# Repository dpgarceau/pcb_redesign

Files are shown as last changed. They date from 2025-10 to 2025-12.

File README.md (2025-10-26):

# AeroJudge PCB Redesign - Board Consolidation Project

**Goal:** Merge two existing boards plus three sub-modules into a single Raspberry Pi 4 HAT for streamlined production.

This project consolidates a multi-board assembly into one functional HAT PCB suitable for commercial manufacturing (JLCPCB-A or similar).

## Project Overview

Currently, the AeroJudge system consists of:
- Main board (primary interface and controls)
- Power board with three mounted sub-modules
- Multiple interconnecting cables

**Target:** Single PCB design with all functionality integrated, ready for automated assembly.

## Files Included

- `Main_Board.kicad_pcb` / `Main_Board.kicad_sch` - Primary interface board
- `Power_Board.kicad_pcb` / `Power_Board.kicad_sch` - Power management board
- `Pololu_2810_Circuit.pdf` - Circuit diagram for power switch implementation
- Sub-board reference links and datasheets (see below)

## Main Board Changes

**Components to Remove:**
- ENC 1 (keep ENC2 only)
- GPIO16, GPIO12, GPIO23, GPIO18
- All I2C connectors except I2C-1 (which will be integrated on-board)
- Backside pads for poweroff select and shutdown select (replace with direct traces to GPIO24 and GPIO25)

## Power Board Integration

The power board currently uses three separate sub-modules that must be integrated directly onto the main PCB:

### 1. INA226 Current/Voltage Sensor
- Reference module: https://www.aliexpress.us/item/3256806274363321.html
- Function: Battery monitoring
- Designer should integrate equivalent circuit based on INA226 datasheet

### 2. Pololu 2810 Power Switch
- Circuit diagram provided: `Pololu_2810_Circuit.pdf`
- Use this circuit diagram to integrate switch functionality onto main board
- No pre-made module needed

### 3. Voltage Regulator (Requires Redesign)
- Current setup uses manual voltage adjustment (not optimal)
- **Requirements:** 5.1V DC output, 3+ Amp capability for Raspberry Pi 4
- **Options:**
  - Clone Pololu 4892 circuit (5V, 3.4A Step-Down Voltage Regulator D30V30F)
  - Design equivalent buck converter circuit
  - Designer should recommend specific components/circuit

**Power Input:**
- Replace current battery solder pads with appropriate DC power connector/plug
- Specify connector type in design

**Connectors Being Eliminated:**
All external connectors between boards become internal traces:
- I2C connectors
- Power/shutoff connectors  
- 5V battery connector

## Additional Requirements

### LED Connector
- Duplicate existing LED connector
- Add second connector for 3.3V LED operation
- Designer should specify connector types

### Physical Constraints
- Base on Raspberry Pi 4 HAT form factor (can be larger if needed - maximum size without case redesign shown in `AeroJudge_PCB-Size.pdf`, provide size recommendations if that is not large enough)
- **Connector height limit:** Approximately 5mm (90-degree connectors required for case clearance)
- Components can be on both sides of board
- **Avoid placing connectors on bottom side** (HAT clearance requirements)
- Existing case can be redesigned if necessary, but prefer to work within current constraints

### Board Markings
- Front: AeroJudge logo, website link, "Board Rev 3.0"
- Rear: IMAC logo (if space permits, not critical)

## Deliverables Expected

1. Complete KiCad project files (schematics + PCB layout)
2. Manufacturing-ready Gerber files
3. Bill of Materials (BOM) with specific part numbers
4. Assembly drawing/notes
5. Board size recommendations based on component layout

## Design Notes

- Target manufacturer: JLCPCB-A or similar automated assembly service
- All sub-assemblies must be eliminated - single PCB only
- Maintain all existing functionality from current two-board system
- Designer should flag any potential issues with integration approach

## Questions for Designer

Before starting, please confirm:
1. Are the provided sub-board references sufficient, or do you need additional datasheets?
2. What board dimensions do you recommend based on component density?
3. Any concerns about the voltage regulator redesign requirements?

## Contact

For questions or clarifications during design process, please contact me through upwork.

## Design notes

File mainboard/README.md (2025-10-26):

# AeroJudge PCB

Here you will find details and source files for the aerojudge main PCB.  This PCB can be used standalone or together with the Aerojudge Power PCB.
<picture>
  <source
    srcset="AeroJudge_PCB_Top.jpg"
    media="(orientation: landscape)" />
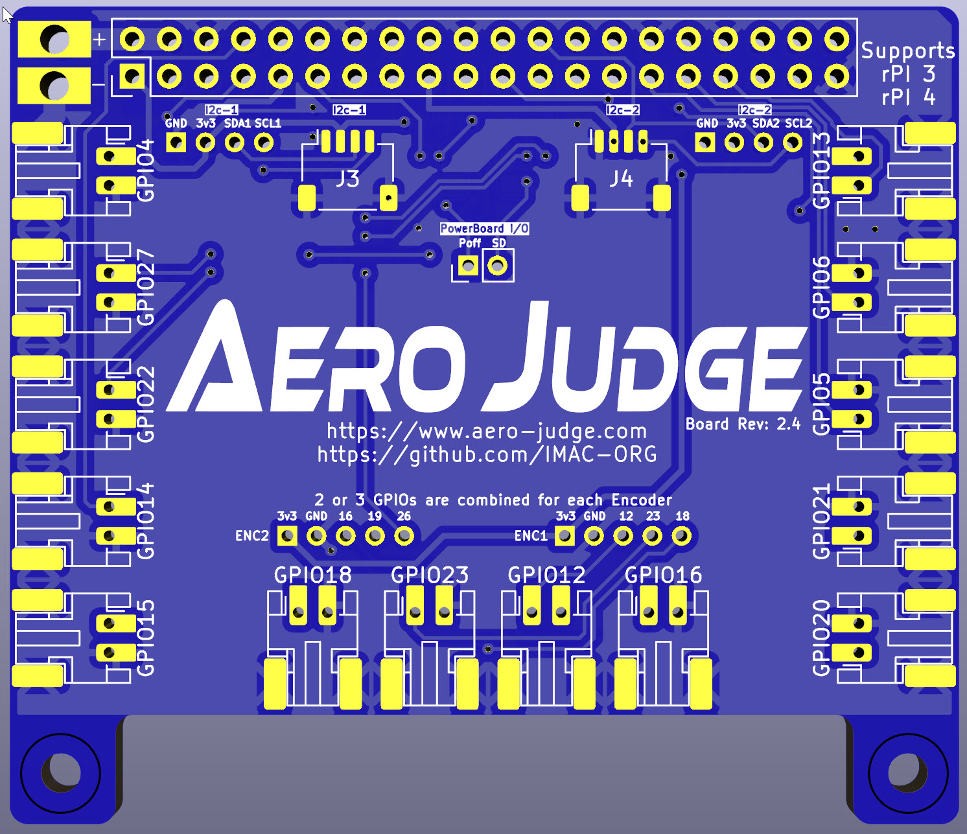
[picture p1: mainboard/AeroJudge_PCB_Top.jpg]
AeroJudge PCB Top
  
</picture>
<picture>
  <source
    srcset="AeroJudge_PCB_Bottom.jpg"
    media="(orientation: landscape)" />
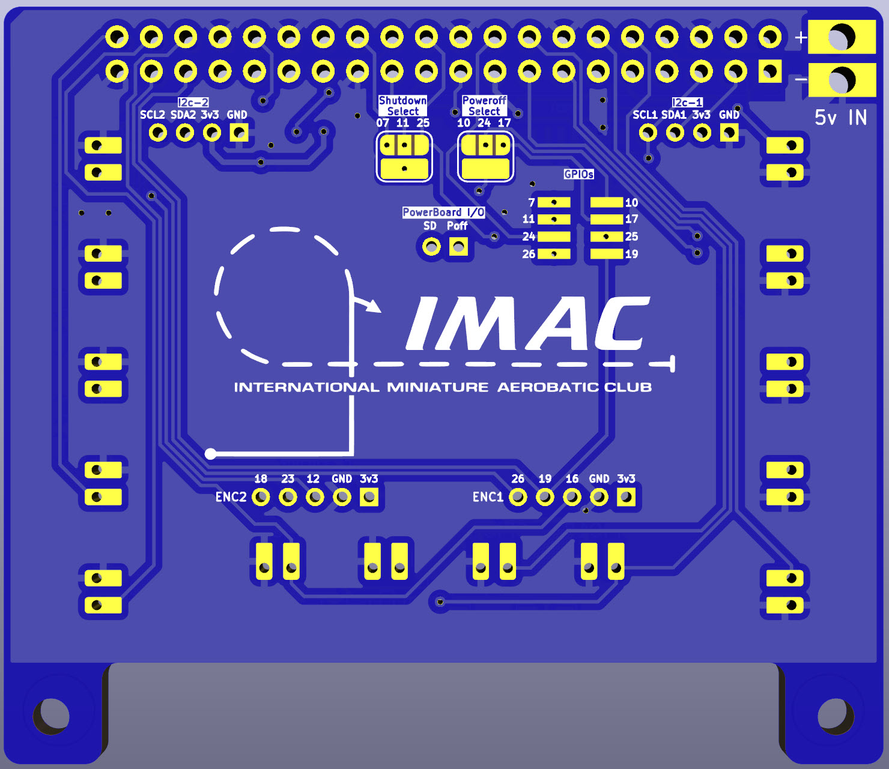
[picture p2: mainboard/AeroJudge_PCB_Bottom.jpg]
AeroJudge PCB Bottom
  
</picture>

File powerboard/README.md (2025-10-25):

# AeroJudge PCB

<picture>
  <source
    srcset="../..//Media/AeroJudge%20Logo/AeroJudge%20Logo.jpg"
    media="(orientation: landscape)" />
  AeroJudge
</picture>
<br>

Here you will find details and source files for the aerojudge powerboard PCB.  This PCB is used to house the power components of the device.

<picture>
  <source
    srcset="AeroJudge_Powerboard_PCB_Top.png"
    media="(orientation: landscape)" />
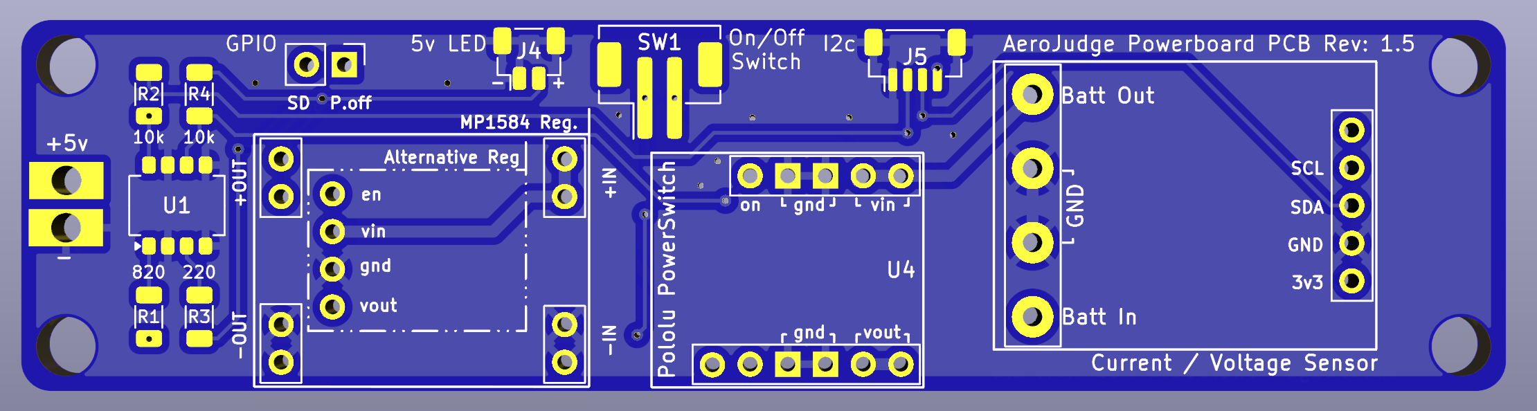
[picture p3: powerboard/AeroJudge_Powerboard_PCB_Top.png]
AeroJudge Powerboard PCB Top
  
</picture>
<picture>
  <source
    srcset="AeroJudge_Powerboard_PCB_Bottom.png"
    media="(orientation: landscape)" />
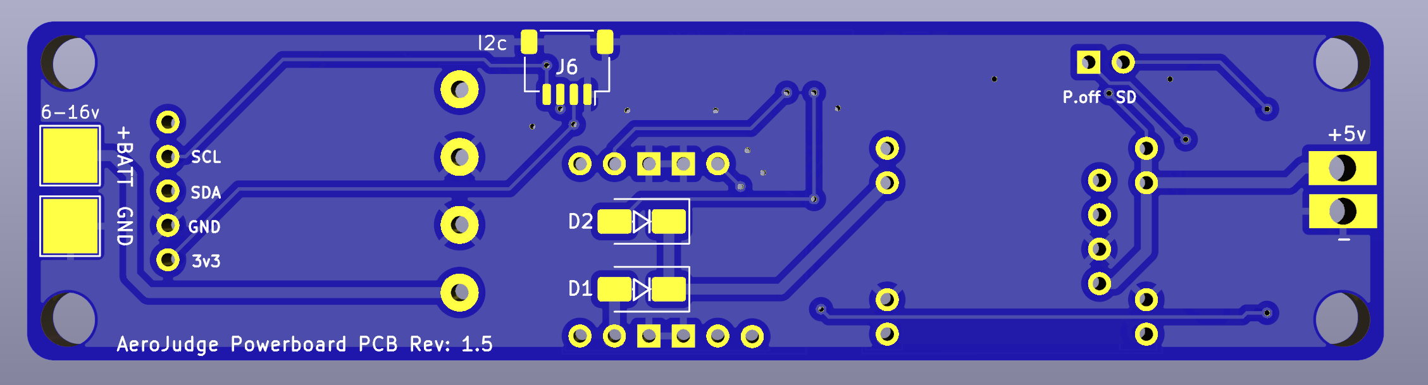
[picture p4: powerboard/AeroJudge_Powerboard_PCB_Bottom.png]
AeroJudge Powerboard PCB Bottom
  
</picture>
<br>

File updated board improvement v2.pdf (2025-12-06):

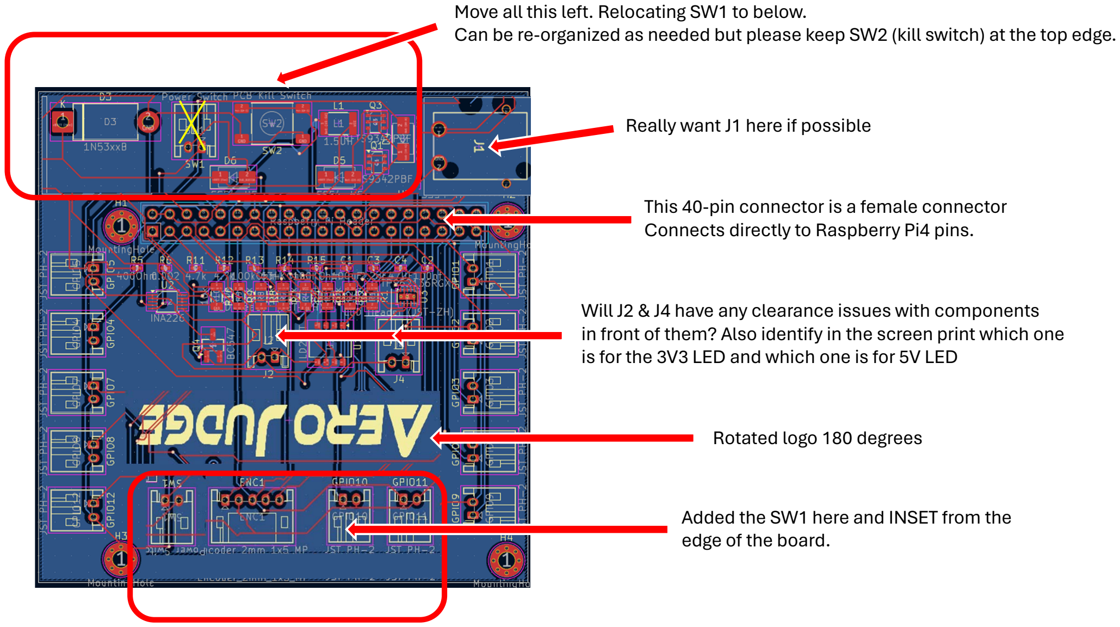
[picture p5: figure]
Really want J1 here if possible; Rotated logo 180 degrees; Added the SW1 here and INSET from the edge of the board.

Move all this left. Relocating SW1 to below.
Can be re-organized as needed but please keep SW2 (kill switch) at the top edge.

This 40-pin connector is a female connector Connects directly to Raspberry Pi4 pins.

Will J2 & J4 have any clearance issues with components in front of them? Also identify in the screen print which one is for the 3V3 LED and which one is for 5V LED

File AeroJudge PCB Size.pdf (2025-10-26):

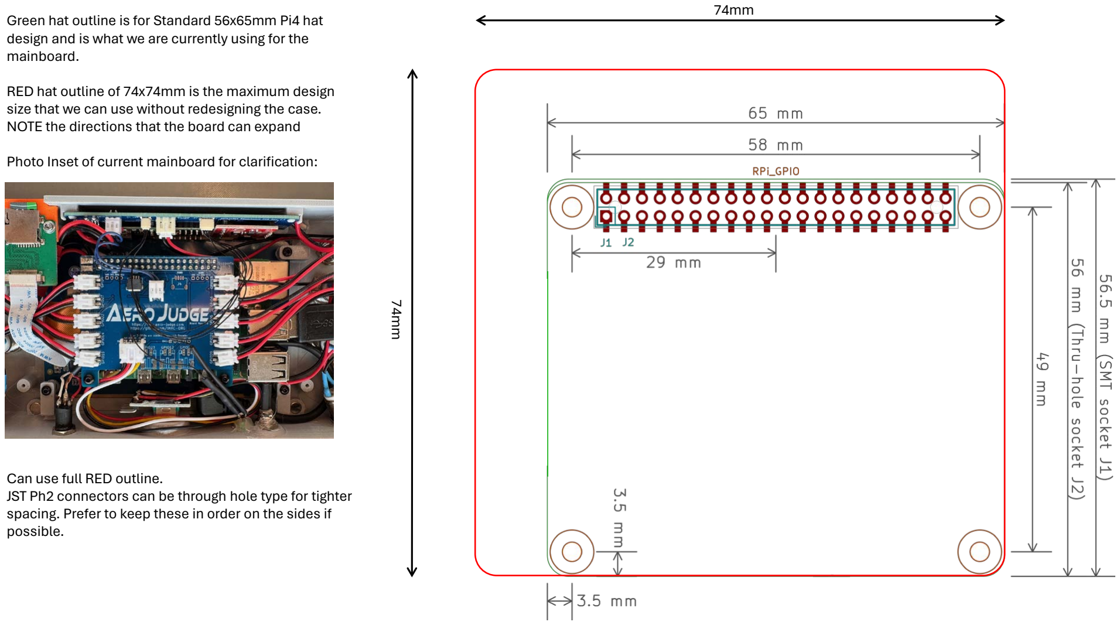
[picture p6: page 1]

74mm

74mm

Green hat outline is for Standard 56x65mm Pi4 hat design and is what we are currently using for the mainboard.

RED hat outline of 74x74mm is the maximum design size that we can use without redesigning the case. NOTE the directions that the board can expand

Photo Inset of current mainboard for clarification:

Can use full RED outline.
JST Ph2 connectors can be through hole type for tighter spacing. Prefer to keep these in order on the sides if possible.

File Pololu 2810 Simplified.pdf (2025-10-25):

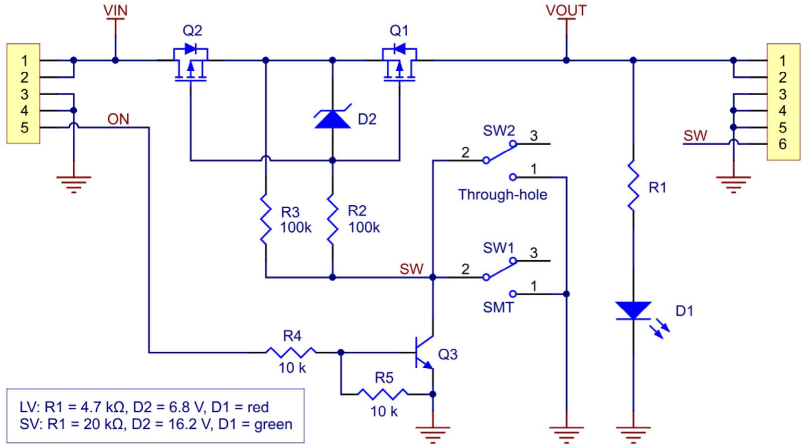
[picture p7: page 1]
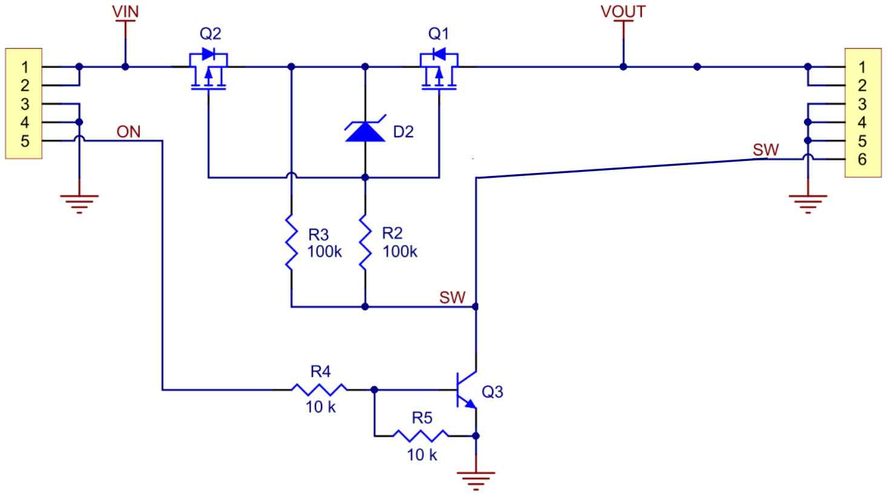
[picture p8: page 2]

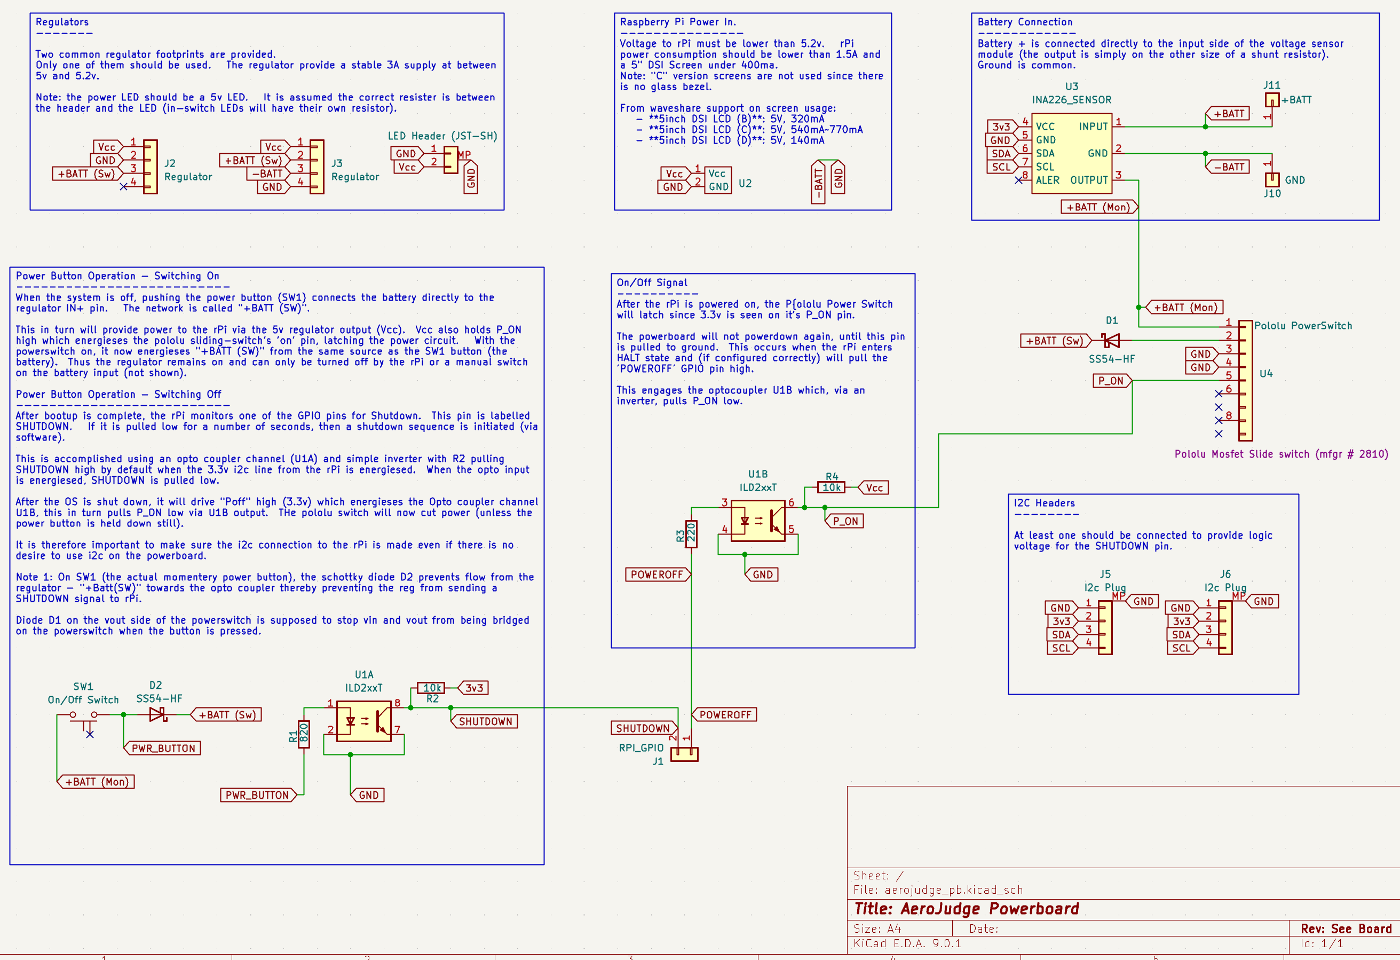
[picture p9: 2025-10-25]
powerboard/aerojudge_pb_SCHEMATIC.png

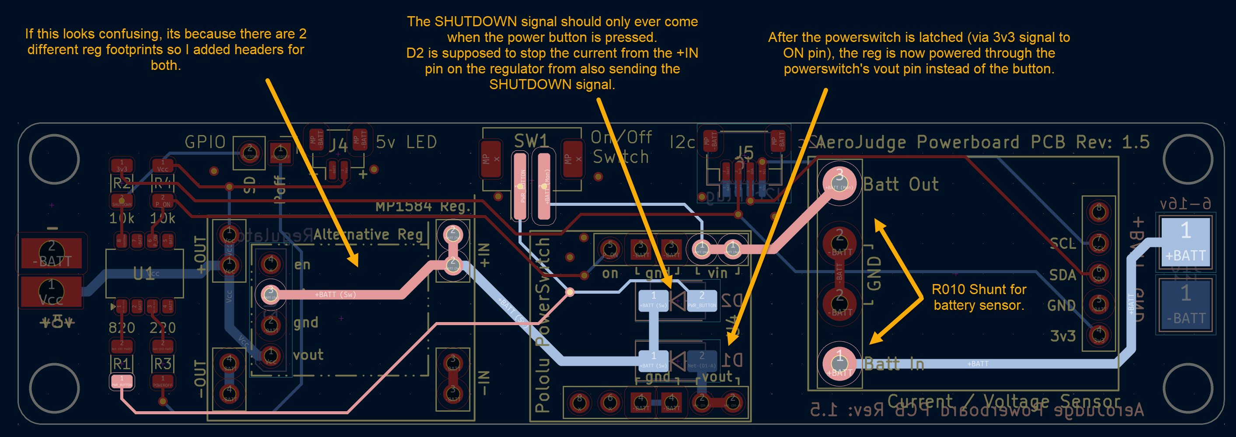
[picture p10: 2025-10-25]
powerboard/aerojudge_pb_ON_BUTTON.png

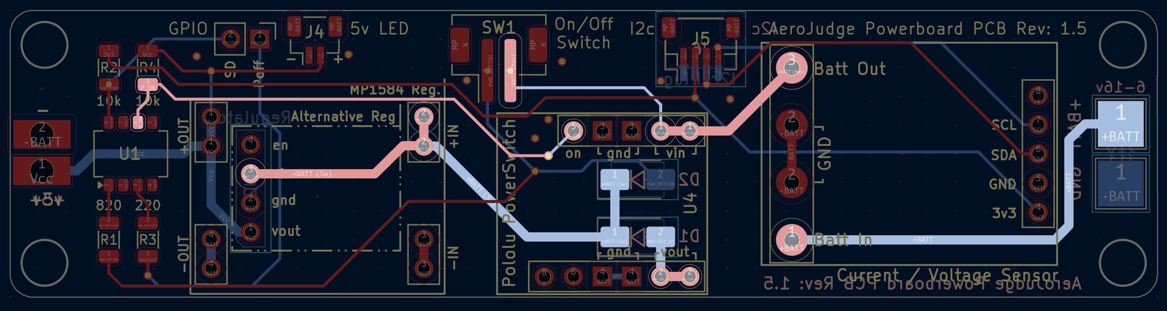
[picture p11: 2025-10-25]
powerboard/aerojudge_pb_ON_LATCHED.png

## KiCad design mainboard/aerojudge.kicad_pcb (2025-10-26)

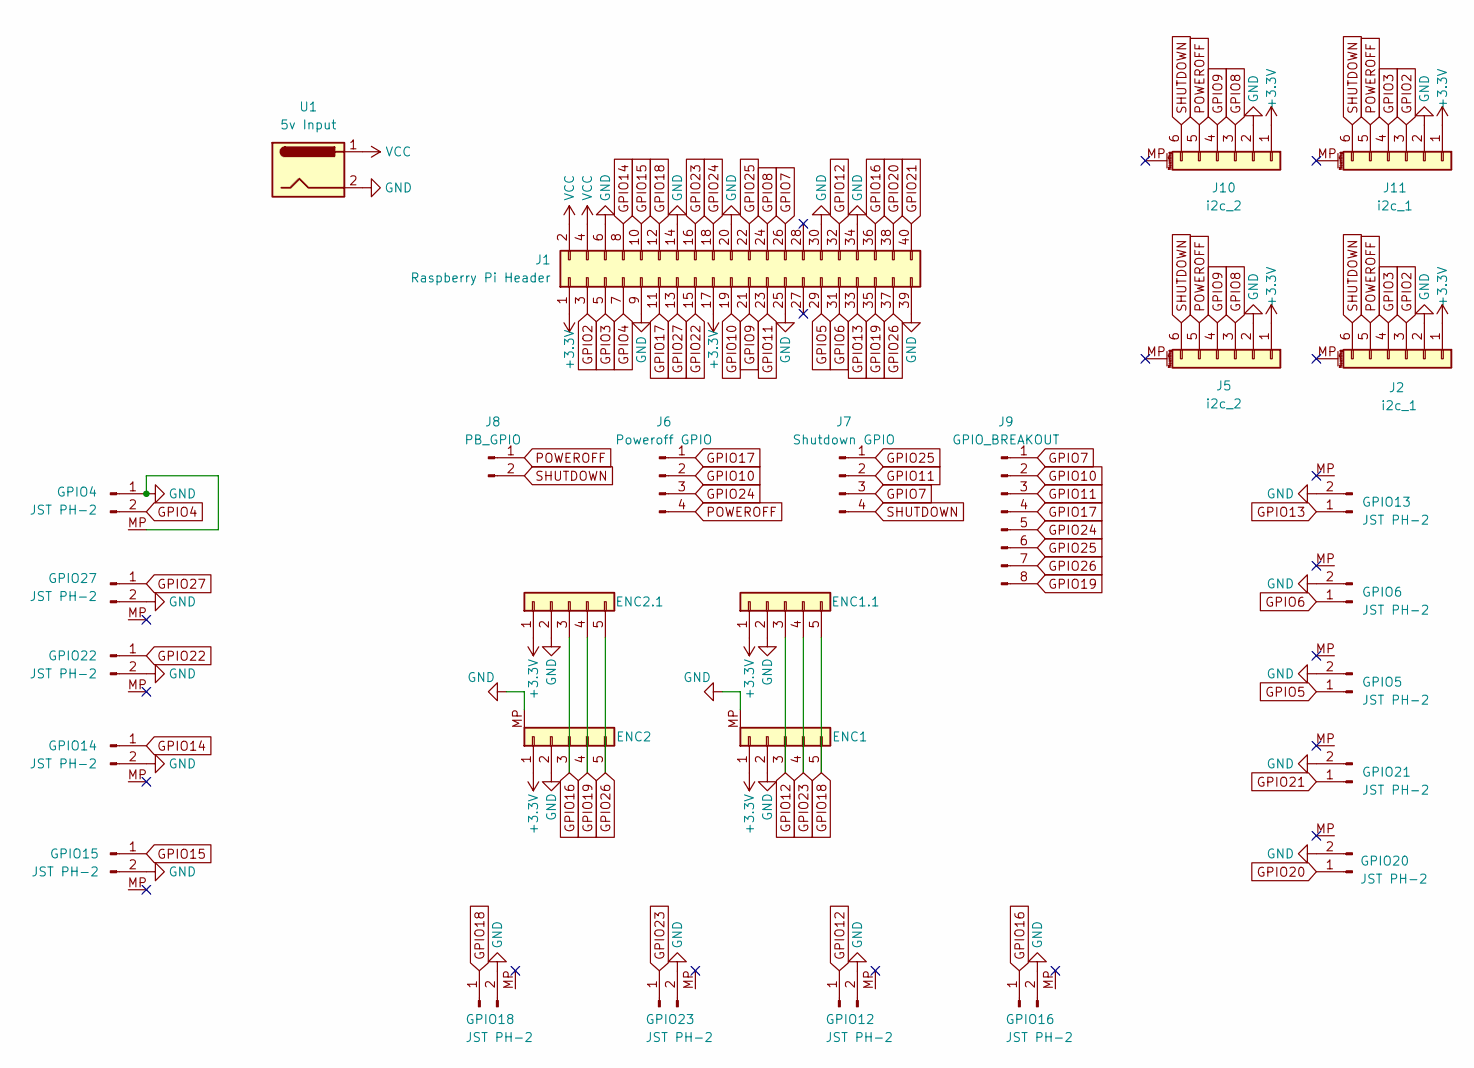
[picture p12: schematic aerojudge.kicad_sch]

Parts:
ENC1, ENC2: Encoder_2mm_1x5_MP; JST_PH_S5B-PH-SM4-TB_1x05-1MP_P2.00mm_Horizontal
ENC1.1, ENC2.1: Conn_01x05; PinHeader_1x05_P2.00mm_Vertical
GPIO4, GPIO5, GPIO6, GPIO12, GPIO13, GPIO14, GPIO15, GPIO16, GPIO18, GPIO20, GPIO21, GPIO22, GPIO23, GPIO27: JST PH-2; JST_PH_S2B-PH-K_1x02_P2.00mm_Horizontal_MP
J1: Raspberry Pi Header; PinHeader_2x20_P2.54mm_RPI
J2: i2c_1; JST_PH_S6B-PH-SM4-TB_1x06-1MP_P2.00mm_Horizontal
J5: i2c_2; JST_PH_S6B-PH-SM4-TB_1x06-1MP_P2.00mm_Horizontal
J6: Poweroff GPIO; SolderJumperSelector_3PIN_P3_Default
J7: Shutdown GPIO; SolderJumperSelector_3PIN_P1_Default
J8: PB_GPIO; PinHeader_1x02_P2.00mm_Vertical
J9: GPIO_BREAKOUT; PinHeader_2x04_P1.27mm_Vertical_SMD_NoBorder
J10: i2c_2; JST_SH_SM06B-SRSS-TB_1x06-1MP_P1.00mm_Horizontal
J11: i2c_1; JST_SH_SM06B-SRSS-TB_1x06-1MP_P1.00mm_Horizontal
U1: 5v Input; Solder_Pads

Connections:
+3.3V: ENC1.1, ENC1.1.1, ENC2.1, ENC2.1.1, J1.1, J1.17, J2.1, J5.1, J10.1, J11.1
GND: ENC1.2, ENC1.MP, ENC1.1.2, ENC2.2, ENC2.MP, ENC2.1.2, GPIO4.1, GPIO4.MP, GPIO5.2, GPIO6.2, GPIO12.2, GPIO13.2, GPIO14.2, GPIO15.2, GPIO16.2, GPIO18.2, GPIO20.2, GPIO21.2, GPIO22.2, GPIO23.2, GPIO27.2, J1.6, J1.9, J1.14, J1.20, J1.25, J1.30, J1.34, J1.39, J2.2, J5.2, J10.2, J11.2, U1.2
GPIO2: J1.3, J2.3, J11.3
GPIO3: J1.5, J2.4, J11.4
GPIO4: GPIO4.2, J1.7
GPIO5: GPIO5.1, J1.29
GPIO6: GPIO6.1, J1.31
GPIO7: J1.26, J7.3, J9.1
GPIO8: J1.24, J5.3, J10.3
GPIO9: J1.21, J5.4, J10.4
GPIO10: J1.19, J6.2, J9.2
GPIO11: J1.23, J7.2, J9.3
GPIO12: ENC1.3, ENC1.1.3, GPIO12.1, J1.32
GPIO13: GPIO13.1, J1.33
GPIO14: GPIO14.1, J1.8
GPIO15: GPIO15.1, J1.10
GPIO16: ENC2.3, ENC2.1.3, GPIO16.1, J1.36
GPIO17: J1.11, J6.1, J9.4
GPIO18: ENC1.5, ENC1.1.5, GPIO18.1, J1.12
GPIO19: ENC2.4, ENC2.1.4, J1.35, J9.8
GPIO20: GPIO20.1, J1.38
GPIO21: GPIO21.1, J1.40
GPIO22: GPIO22.1, J1.15
GPIO23: ENC1.4, ENC1.1.4, GPIO23.1, J1.16
GPIO24: J1.18, J6.3, J9.5
GPIO25: J1.22, J7.1, J9.6
GPIO26: ENC2.5, ENC2.1.5, J1.37, J9.7
GPIO27: GPIO27.1, J1.13
POWEROFF: J2.5, J5.5, J6.4, J8.1, J10.5, J11.5
SHUTDOWN: J2.6, J5.6, J7.4, J8.2, J10.6, J11.6
VCC: J1.2, J1.4, U1.1

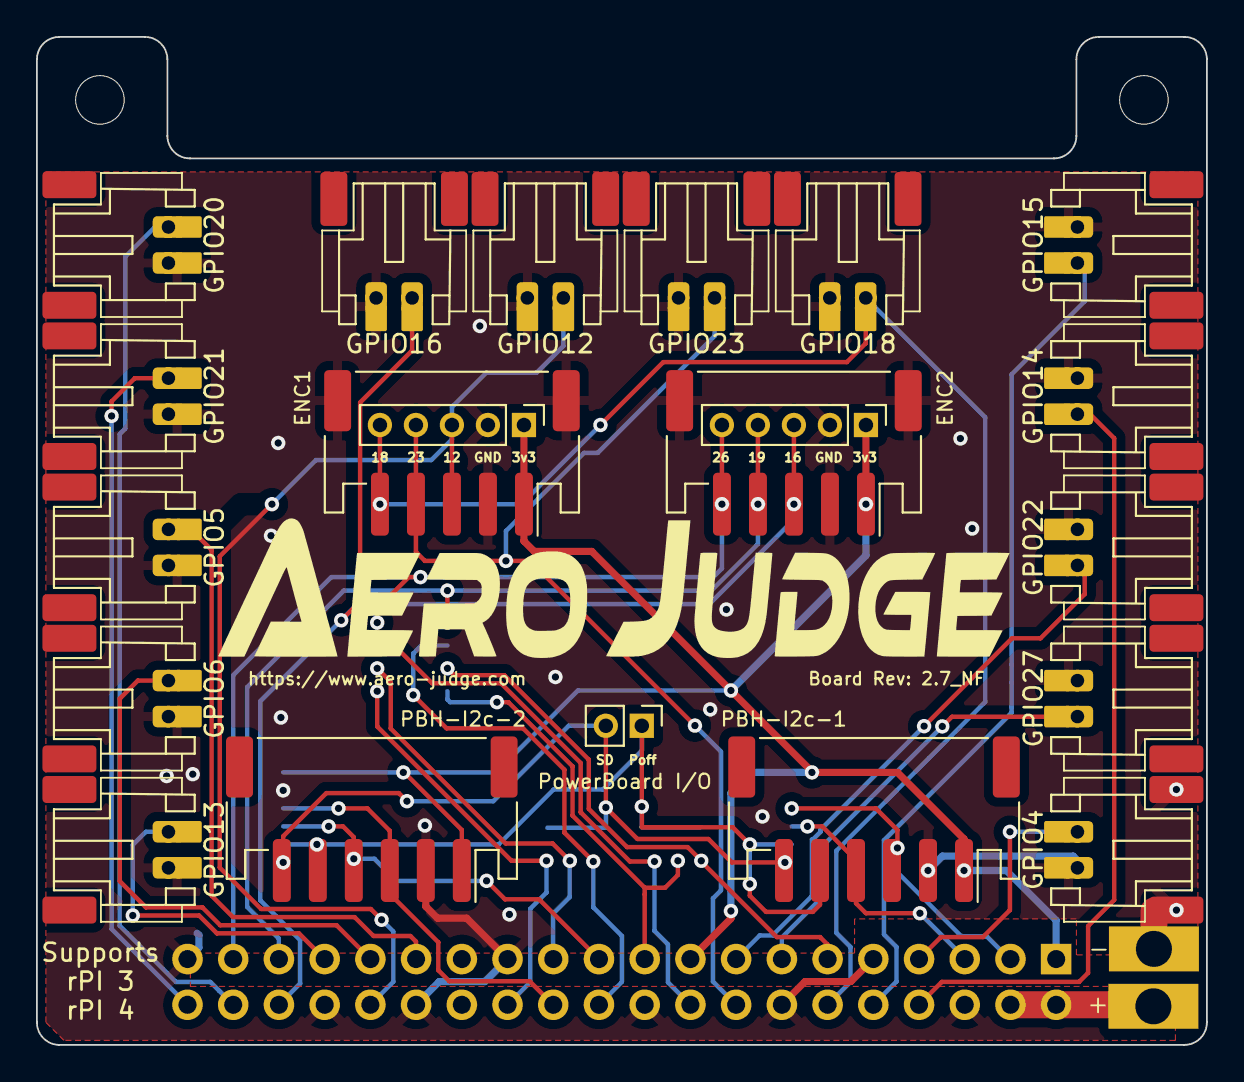
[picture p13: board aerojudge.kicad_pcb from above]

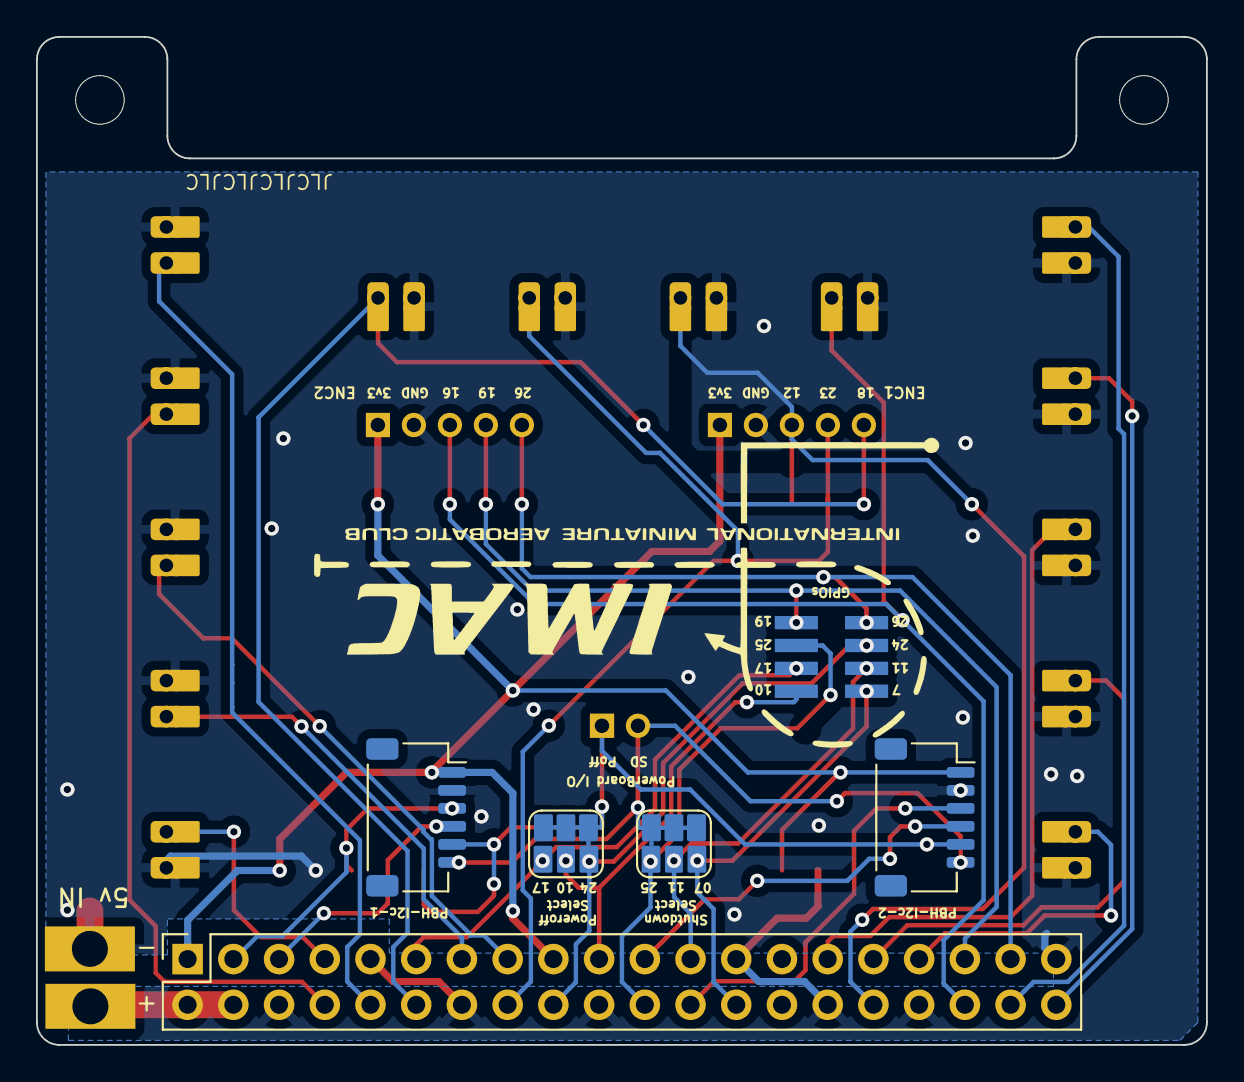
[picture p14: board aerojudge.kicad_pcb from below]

Board: 2 copper layers, 65.0 x 56.0 mm, 30 parts (7 on the bottom side), 31 nets.

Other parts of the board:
AEROJUDGE_LOGO: LOGO; AEROJUDGE_LOGO
IMAC_LOGO: LOGO; IMAC_LOGO

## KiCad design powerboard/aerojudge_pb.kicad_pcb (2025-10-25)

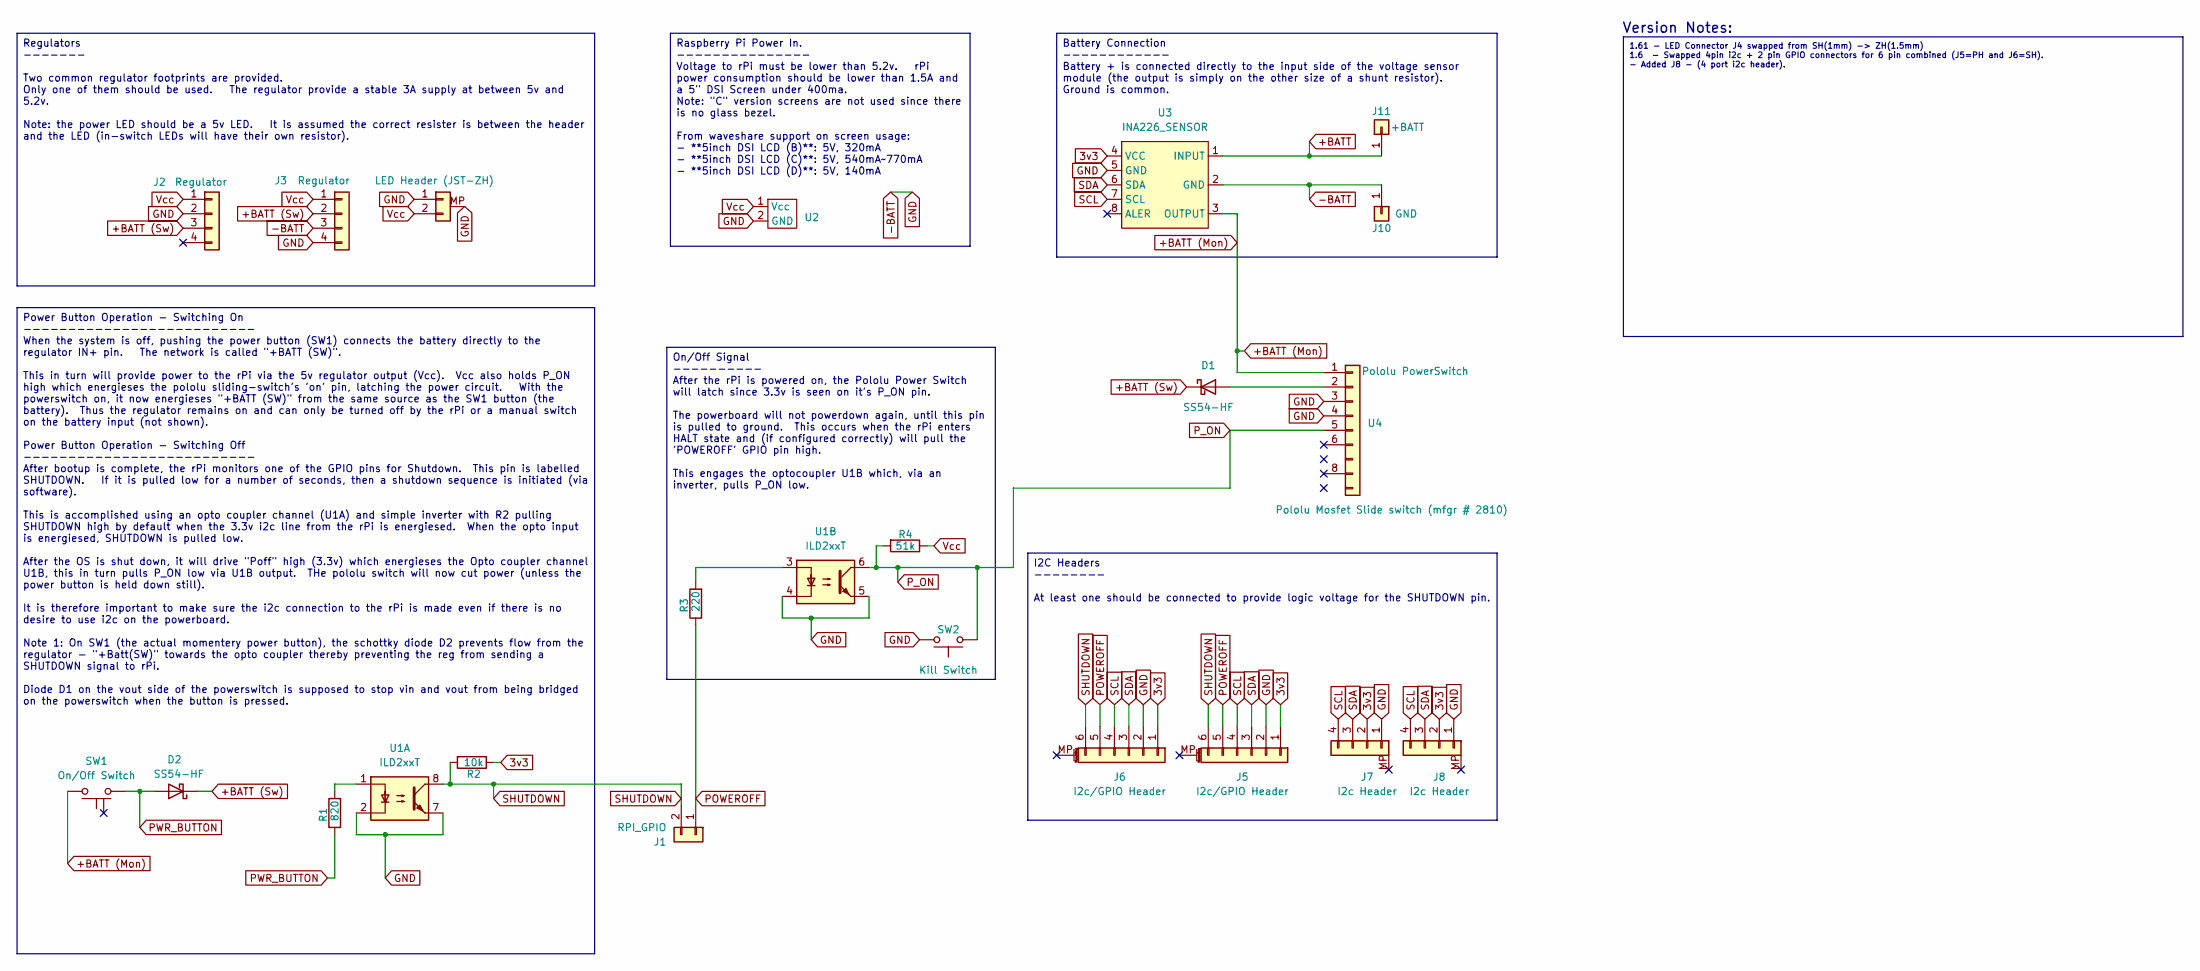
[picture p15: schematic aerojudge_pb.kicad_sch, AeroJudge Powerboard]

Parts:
D1, D2: SS54-HF; D_SMA
J1: RPI_GPIO; SolderJumper-2_P2.54mm_Open_Pad2.0x2.5mm
J2: Regulator; PinHeader_1x04_P2.54mm_Vertical_NoBorder
J3: Regulator; MP1584EN_Regulator
J4: LED Header (JST-ZH); JST_ZH_B2B-ZR-SM4-TF_1x02-1MP_P1.50mm_Vertical
J5: I2c/GPIO Header; JST_PH_B6B-PH-SM4-TB_1x06-1MP_P2.00mm_Vertical
J6: I2c/GPIO Header; JST_SH_BM06B-SRSS-TB_1x06-1MP_P1.00mm_Vertical
J7, J8: I2c Header; JST_SH_SM04B-SRSS-TB_1x04-1MP_P1.00mm_Horizontal
J10: GND; TestPoint_Pad_4.0x4.0mm
J11: +BATT; TestPoint_Pad_4.0x4.0mm
R1: 820; R_1206_3216Metric
R2: 10k; R_1206_3216Metric
R3: 220; R_1206_3216Metric
R4: 51k; R_1206_3216Metric
SW1: On/Off Switch; JST_PH_B2B-PH-SM4-TB_1x02-1MP_P2.00mm_Vertical
SW2: Kill Switch; SW_Push_SPST_NO_Alps_SKRK
U1: ILD2xxT; SOIC-8_6.6x6.27mm_P1.27mm
U2: Solder_Pads
U3: INA226_SENSOR
U4: Pololu PowerSwitch; Mini MOSFET Slide Switch

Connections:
3v3: J5.1, J6.1, J7.2, J8.2, R2.1, U3.4 (VCC)
+BATT: J11.1, U3.1 (INPUT)
+BATT (Mon): SW1.2, U3.3 (OUTPUT), U4.1
+BATT (Sw): D1.1 (K), D2.1 (K), J2.3, J3.2
-BATT: J2.2, J3.3, J3.4, J4.1, J4.MP, J5.2, J6.2, J7.1, J8.1, J10.1, SW2.2, U1.2, U1.4, U1.5, U1.7, U2.2 (GND), U3.2 (GND), U3.5 (GND), U4.3, U4.4
unnamed: D1.2 (A), U4.2
unnamed: R1.2, U1.1
unnamed: R3.2, U1.3
POWEROFF: J1.1, J5.5, J6.5, R3.1
PWR_BUTTON: D2.2 (A), R1.1, SW1.1
P_ON: R4.2, SW2.1, U1.6, U4.5
SCL: J5.4, J6.4, J7.4, J8.4, U3.7 (SCL)
SDA: J5.3, J6.3, J7.3, J8.3, U3.6 (SDA)
SHUTDOWN: J1.2, J5.6, J6.6, R2.2, U1.8
Vcc: J2.1, J3.1, J4.2, R4.1, U2.1 (Vcc)

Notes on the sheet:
Version Notes:
Battery Connection ------------ Battery + is connected directly to the input side of the voltage sensor module (the output is simply on the other size of a shunt resistor). Ground is common.
I2C Headers -------- At least one should be connected to provide logic voltage for the SHUTDOWN pin.
Regulators ------- Two common regulator footprints are provided. Only one of them should be used. The regulator provide a stable 3A supply at between 5v and 5.2v. Note: the power LED should be a 5v LED. It is assumed the correct resister is between the header and the LED (in-switch LEDs will have t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
Power Button Operation - Switching On -------------------------- When the system is off, pushing the power button (SW1) connects the battery directly to the regulator IN+ pin. The network is called "+BATT (SW)". This in turn will provide power to the rPi via the 5v regulator output (Vcc). Vcc also 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
1.61 - LED Connector J4 swapped from SH(1mm) -> ZH(1.5mm) 1.6 - Swapped 4pin i2c + 2 pin GPIO connectors for 6 pin combined (J5=PH and J6=SH). - Added J8 - (4 port i2c header).
On/Off Signal ---------- After the rPi is powered on, the Pololu Power Switch will latch since 3.3v is seen on it's P_ON pin. The powerboard will not powerdown again, until this pin is pulled to ground. This occurs when the rPi enters HALT state and (if configured correctly) will pull the 'POWEROFF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
Raspberry Pi Power In. --------------- Voltage to rPi must be lower than 5.2v. rPi power consumption should be lower than 1.5A and a 5" DSI Screen under 400ma. Note: "C" version screens are not used since there is no glass bezel. From waveshare support on screen usage: - **5inch DSI LCD (B)**: 5V, 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

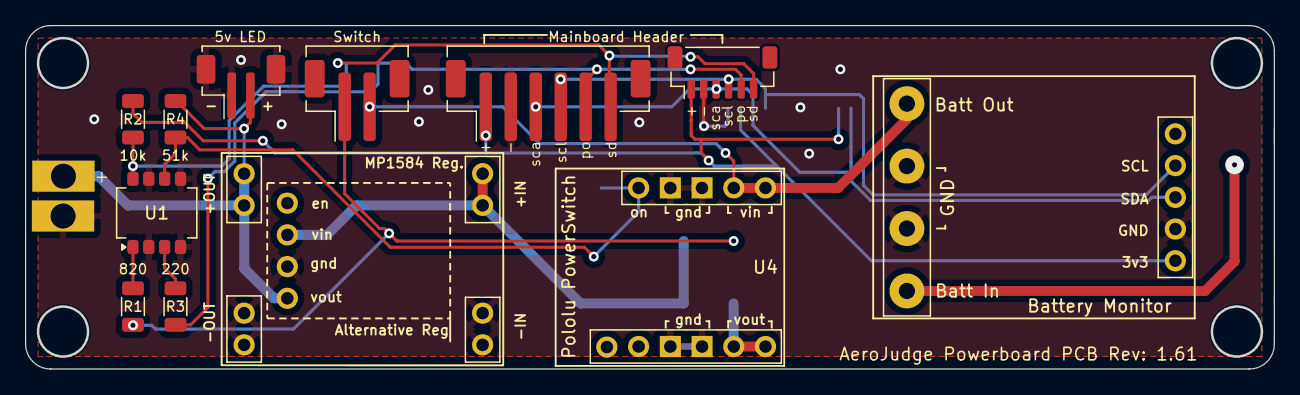
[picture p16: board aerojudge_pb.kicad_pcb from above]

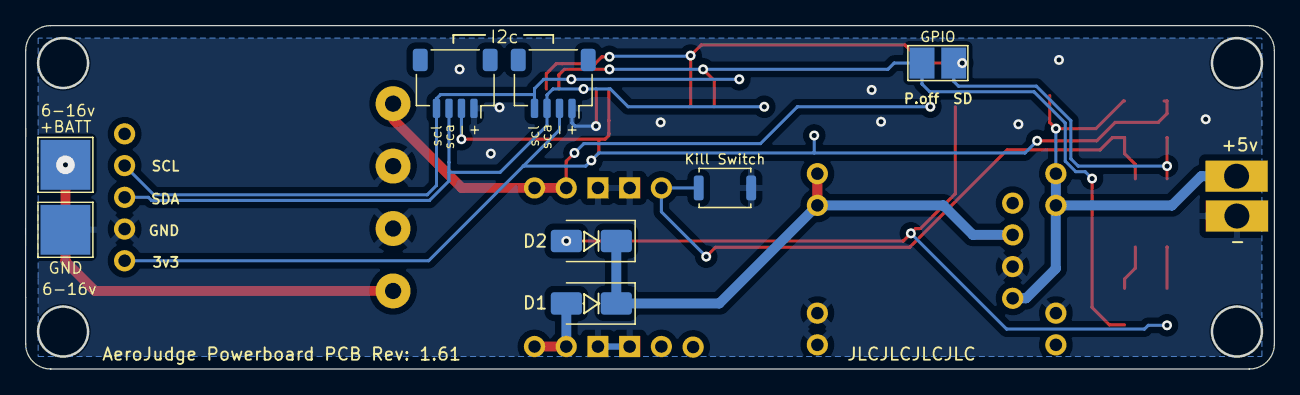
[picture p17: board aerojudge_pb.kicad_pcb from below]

Board: 2 copper layers, 100.0 x 27.5 mm, 22 parts (9 on the bottom side), 15 nets.

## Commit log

2025-10-25 Add initial readme file to powerboard directory
2025-10-25 Enhance README with detailed project specifications
    Expanded project description and clarified design requirements for the PCB redesign.
2025-10-25 Clarify component removal instructions in README
    Updated the README to clarify component removal on the main board.
2025-10-26 Update README with new board design specifications
    Added details about the new main board design and connector requirements.
2025-10-26 Update physical constraints for PCB size recommendations
    Clarified maximum size constraints for PCB design.
2025-11-13 Single Schematic (Draft) and XT30PW-M Specs
    [aerojudge_pcb_dg.kicad_sch]
